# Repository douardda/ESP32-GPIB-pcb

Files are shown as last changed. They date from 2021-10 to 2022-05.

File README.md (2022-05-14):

# ESP32 based GPIB interface - Kicad design files

This is a simple GPIB interface design using an ESP32 board as main controller. It can
(optionally but highly recommanded) use a couple of driver ICs (SN75160 and SN75161/162).

The design consist in 2 boards coupled together: one with the IEEE488 connector and
driver ICs, and one with the Arduino or ESP32 board.

Doing so, the common GPIB board can be used with several Arduino/ESP32 boards.

3D view of the common IEEE488 board:

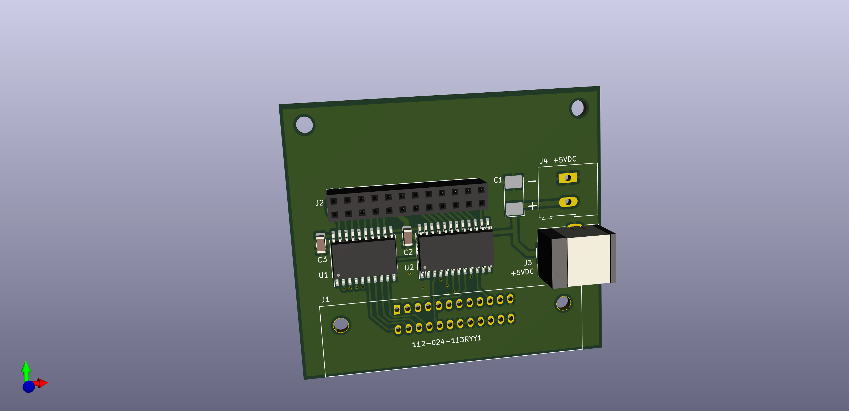
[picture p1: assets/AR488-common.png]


3D view of the interface board for the ESP32-S2-saola:

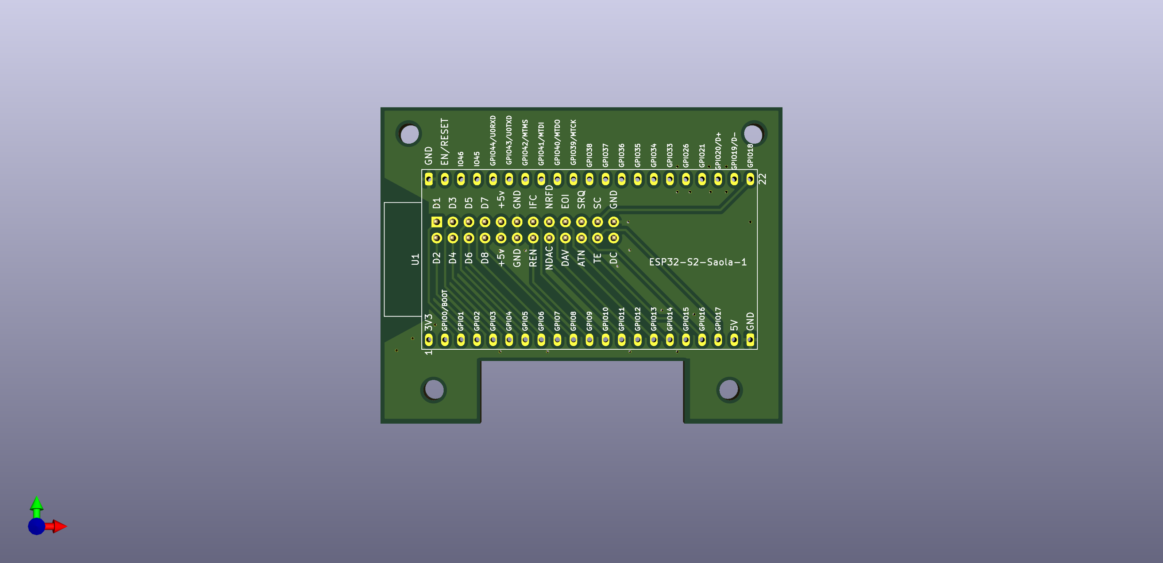
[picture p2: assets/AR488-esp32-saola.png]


3D view of the interface board for the Arduini nano:

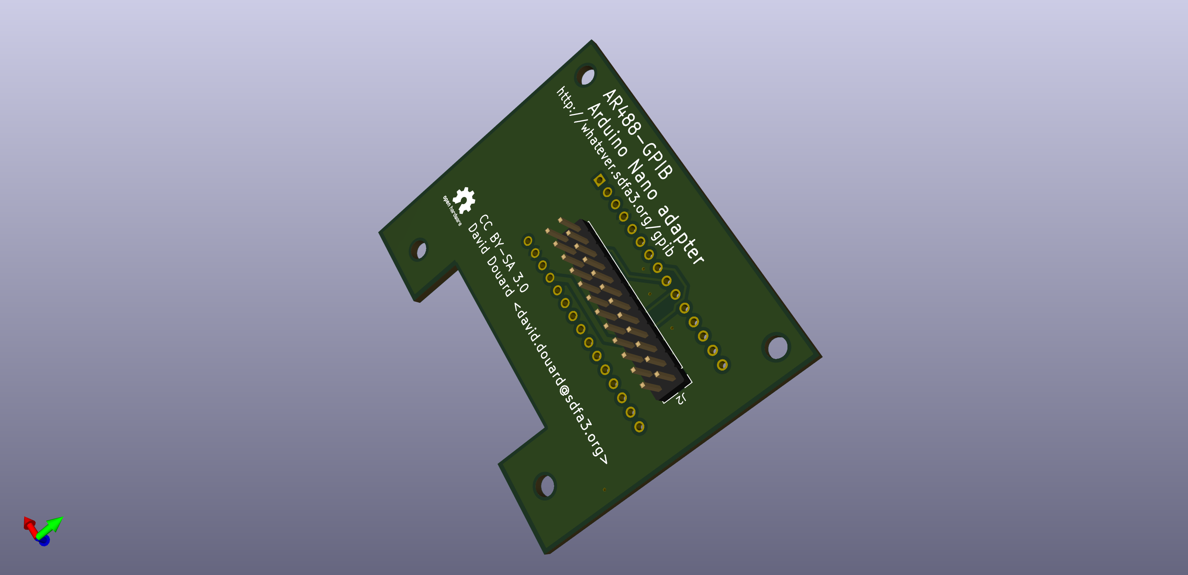
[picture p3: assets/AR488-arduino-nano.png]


Interface using a generic ESP32 Devkit-c board:

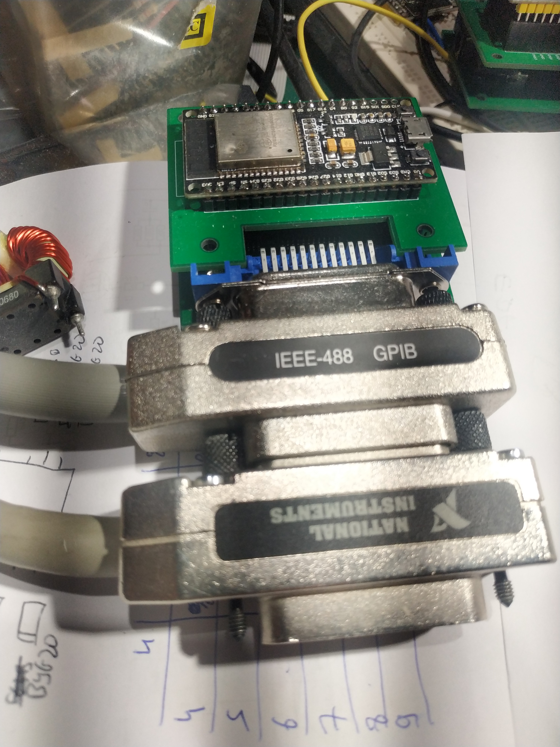
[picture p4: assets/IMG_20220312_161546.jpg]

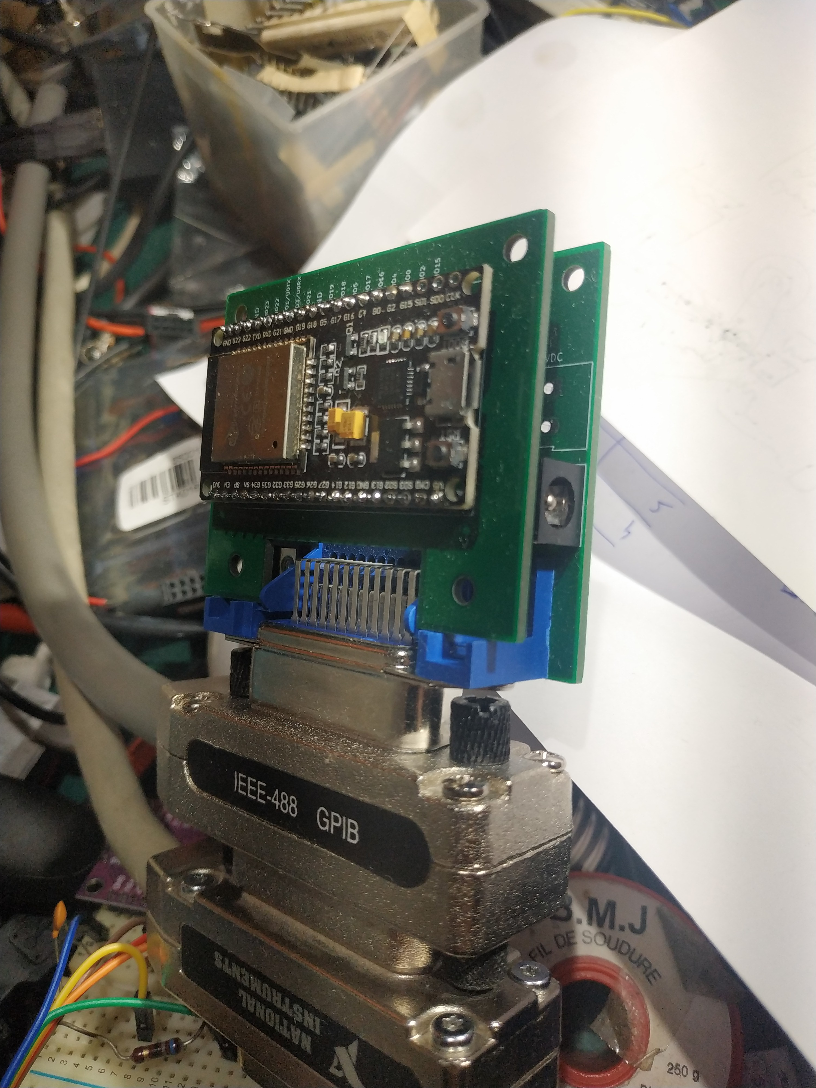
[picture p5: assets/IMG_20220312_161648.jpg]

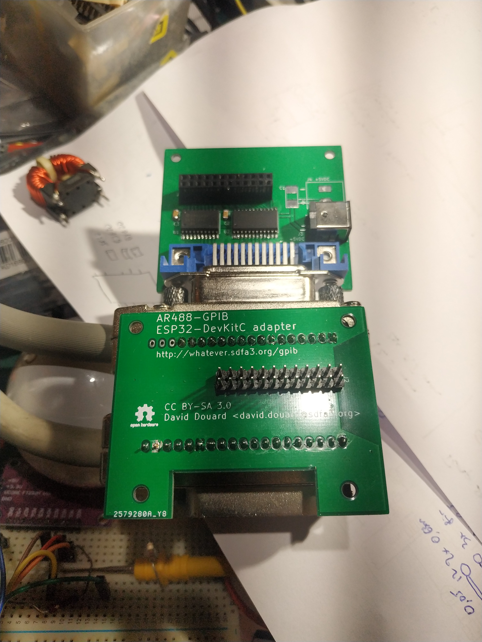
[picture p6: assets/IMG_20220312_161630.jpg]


This design is licensed under the 
[CC-BY-SA 4.0](https://creativecommons.org/licenses/by-sa/4.0/) license.



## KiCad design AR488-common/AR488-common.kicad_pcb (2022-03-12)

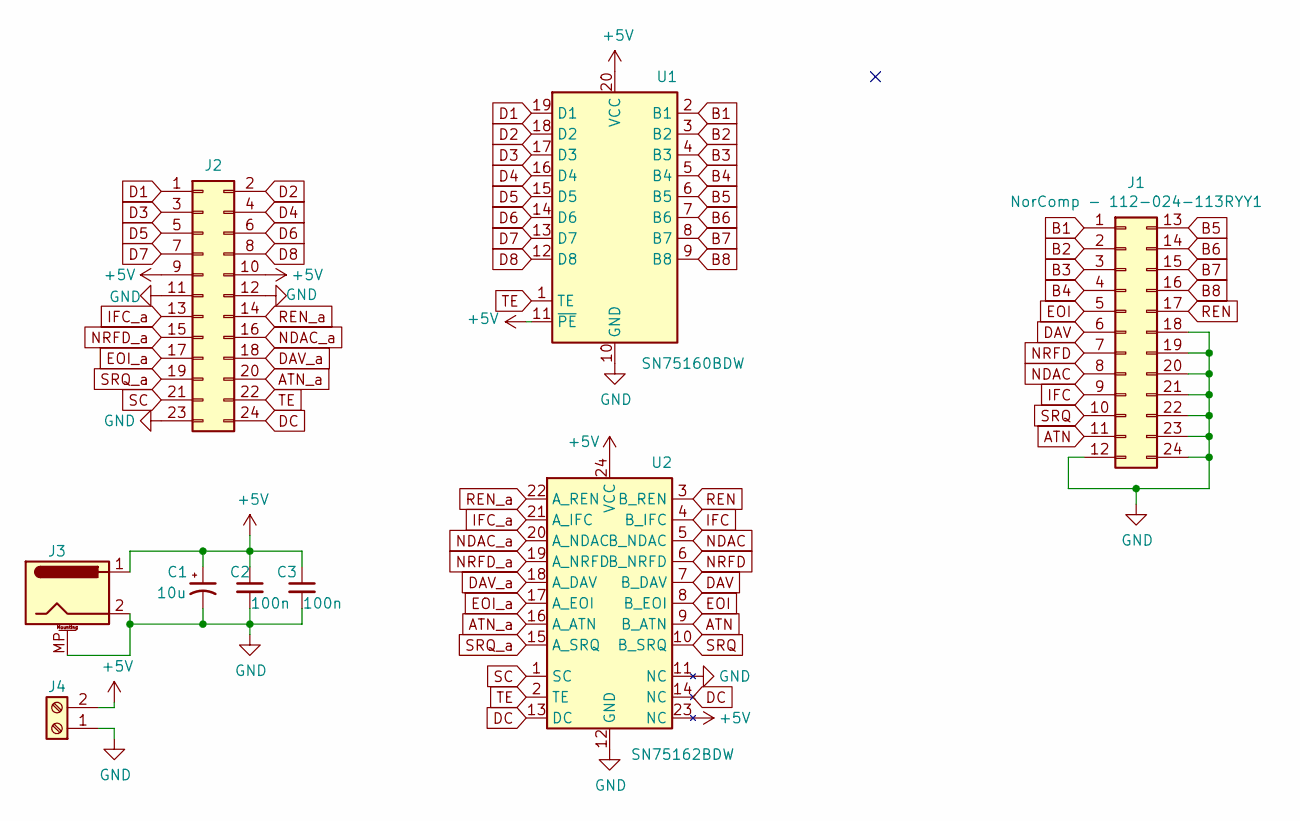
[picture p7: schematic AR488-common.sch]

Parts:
C1: 10u; CP_EIA-7132-20_AVX-U
C2, C3: 100n; C_1206_3216Metric
J1: NorComp - 112-024-113RYY1; CENTRONICS-24
J2: Conn_02x12_Odd_Even; PinSocket_2x12_P2.54mm_Vertical
J3: Barrel_Jack; BarrelJack_CUI_PJ-063AH_Horizontal
J4: Screw_Terminal_01x02; TerminalBlock_Altech_AK300-2_P5.00mm
U1: SN75160BDW; SOIC-20W_7.5x12.8mm_P1.27mm
U2: SN75162BDW; SOIC-24W_7.5x15.4mm_P1.27mm

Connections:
+5V: C1.1, C2.1, C3.1, J2.9, J2.10, J3.1, J4.2, U1.11 (~PE), U1.20 (VCC), U2.23 (NC), U2.24 (VCC)
ATN: J1.11, U2.9 (B_ATN)
ATN_a: J2.20, U2.16 (A_ATN)
B1: J1.1, U1.2 (B1)
B2: J1.2, U1.3 (B2)
B3: J1.3, U1.4 (B3)
B4: J1.4, U1.5 (B4)
B5: J1.13, U1.6 (B5)
B6: J1.14, U1.7 (B6)
B7: J1.15, U1.8 (B7)
B8: J1.16, U1.9 (B8)
D1: J2.1, U1.19 (D1)
D2: J2.2, U1.18 (D2)
D3: J2.3, U1.17 (D3)
D4: J2.4, U1.16 (D4)
D5: J2.5, U1.15 (D5)
D6: J2.6, U1.14 (D6)
D7: J2.7, U1.13 (D7)
D8: J2.8, U1.12 (D8)
DAV: J1.6, U2.7 (B_DAV)
DAV_a: J2.18, U2.18 (A_DAV)
DC: J2.24, U2.13 (DC), U2.14 (NC)
EOI: J1.5, U2.8 (B_EOI)
EOI_a: J2.17, U2.17 (A_EOI)
GND: C1.2, C2.2, C3.2, J1.12, J1.18, J1.19, J1.20, J1.21, J1.22, J1.23, J1.24, J2.11, J2.12, J2.23, J3.2, J3.MP (MountPin), J4.1, U1.10 (GND), U2.11 (NC), U2.12 (GND)
IFC: J1.9, U2.4 (B_IFC)
IFC_a: J2.13, U2.21 (A_IFC)
NDAC: J1.8, U2.5 (B_NDAC)
NDAC_a: J2.16, U2.20 (A_NDAC)
NRFD: J1.7, U2.6 (B_NRFD)
NRFD_a: J2.15, U2.19 (A_NRFD)
REN: J1.17, U2.3 (B_REN)
REN_a: J2.14, U2.22 (A_REN)
SC: J2.21, U2.1 (SC)
SRQ: J1.10, U2.10 (B_SRQ)
SRQ_a: J2.19, U2.15 (A_SRQ)
TE: J2.22, U1.1 (TE), U2.2 (TE)

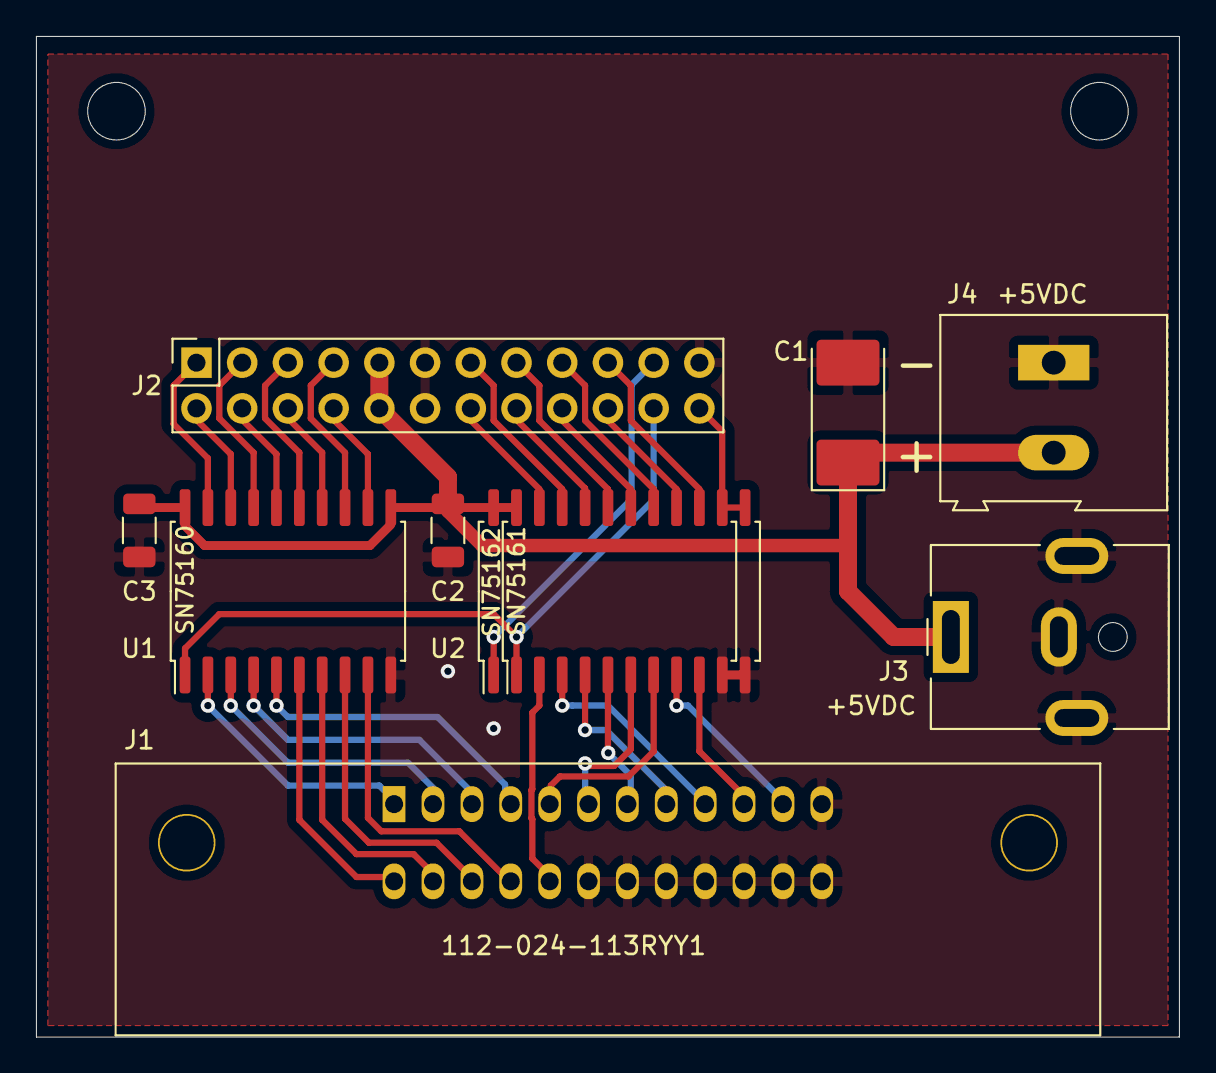
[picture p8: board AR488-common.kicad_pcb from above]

Board: 2 copper layers, 63.5 x 55.6 mm, 9 parts (0 on the bottom side), 37 nets.

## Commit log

2021-10-30 First version of the GPIB/SN7616x board + esp32-saola daughter board
    [AR488-ESP32.kicad_pcb, AR488-ESP32.sch, AR488-esp32-saola.kicad_pcb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]
2021-10-30 Better pin assignment for the inter-PCB connector
    [AR488-ESP32.kicad_pcb, AR488-ESP32.sch, AR488-esp32-saola.kicad_pcb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]
2021-10-31 Finish the commons board + esp32 s2 soala + esp32 devkitc boards
    [AR488-common.kicad_pcb, AR488-common.sch, AR488-esp32-devkitc.kicad_pcb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]
2021-10-31 Add an arduino nano board
    [AR488-arduino-nano.kicad_pcb, AR488-arduino-nano.sch]
2022-03-12 Several minor fixes and adjustments in PCBs
    [AR488-arduino-nano.kicad_pcb, AR488-common.kicad_pcb, AR488-esp32-devkitc.kicad_pcb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]
2022-03-12 Typos in README and add a few pictures of an assembled interface
2022-06-18 Fix the ESP32-devkitc board
    - CMD was connected to GND
    - swap GPIO2 dn GPIO15 to fix boot issues
    [AR488-esp32-devkitc.kicad_pcb, AR488-esp32-devkitc.kicad_sch]

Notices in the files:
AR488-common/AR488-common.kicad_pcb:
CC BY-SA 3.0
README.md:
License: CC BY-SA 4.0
